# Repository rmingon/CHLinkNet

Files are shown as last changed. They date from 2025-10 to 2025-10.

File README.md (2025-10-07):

# CH32V307 Ethernet + PoE Development Board

## Overview

This project is a **custom 4-layer development board** based on the **WCH CH32V307RCT6** RISC-V microcontroller.  
It integrates **Ethernet connectivity**, **USB programming**, and **Power-over-Ethernet (PoE) readiness** through an external module header.

The design was fully created in **KiCad 9.0.3**, including schematic, PCB layout, and 3D mechanical validation.

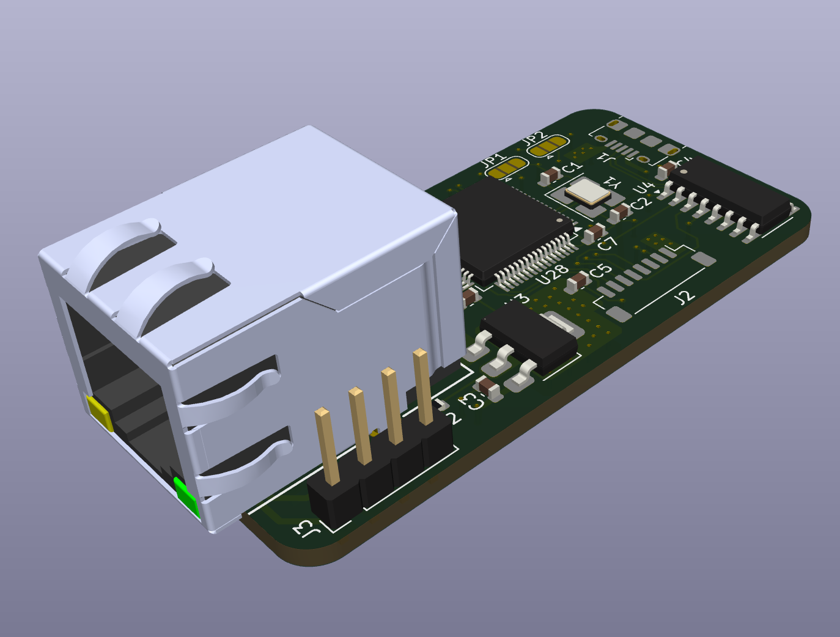
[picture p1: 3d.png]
3d


---

## Key Features

- **MCU:** WCH **CH32V307RCT6**

  - 32-bit RISC-V core @144 MHz
  - 256 KB Flash / 64 KB SRAM
  - Integrated MAC controller for Ethernet
  - USB 2.0 Full-Speed, CAN, ADC, PWM, and multiple GPIOs

- **Ethernet Interface:**

  - **HY931147C** RJ45 connector with integrated magnetics and LEDs
  - RMII interface connected to the CH32V307 MAC peripheral
  - Differential pair routing with impedance control for signal integrity

- **USB Interface:**

  - Micro-USB Type-B connector (J1)
  - **CH340C** USB-to-UART converter for serial programming/debugging
  - USB-powered operation (5 V input)

- **Power Supply:**

  - Input: **5 V** from USB or external PoE module (J3)
  - **LM1117-3.3V** linear regulator provides system 3.3 V rail
  - PoE header allows integration of a DC-DC converter (48 V → 5 V)

- **Clock System:**

  - **25 MHz crystal** (Y1) with 10 pF load capacitors
  - Supports both internal and external oscillators

- **Programming and Debugging:**

  - **1×8 header (J2)** for SWD and UART interface
  - **JP1** (BOOT0) and **JP2** (BOOT1) jumpers for boot mode selection
  - Compatible with WCHISPTool and OpenOCD

- **Status Indicators:**

  - Power LED
  - Dual user LEDs (green and yellow) connected via GPIOs with current-limiting resistors

- **PCB Details:**
  - **4-layer stack-up:**
    - Top: Signal
    - Inner 1: GND plane
    - Inner 2: 3V3 power plane
    - Bottom: Signal
  - Controlled impedance routing for RMII
  - Ground pour under high-speed signals for noise reduction
  - Rounded corners, compact form factor, and 3D-verified mechanical fit

---

## Hardware Architecture

### Power Section

- **Primary Source:** USB 5 V from J1
- **Secondary Source:** PoE module input via J3 header
- **Voltage Regulation:**
  - U3 (LM1117-3.3V) converts 5 V → 3.3 V
  - C4–C6 ensure low-noise decoupling near MCU and PHY
  - Separate power planes on inner layers for 3.3 V and 5 V distribution

### Ethernet Section

- **U1: HY931147C RJ45 connector** with built-in magnetics
- Connected to MCU’s RMII interface pins (TXD, RXD, CRS, REF_CLK, etc.)
- Controlled-impedance differential pairs routed on top layer, referenced to inner GND plane
- Shield and chassis ground isolated via filtering for EMI reduction

### USB-to-UART Interface

- **U4: CH340C** converts USB signals to UART for MCU programming
- Connected to TX_PROG and RX_PROG pins on CH32V307
- Includes pull-up and filtering capacitors for reliable USB operation

### Clock and Reset Circuit

- **Y1: 25 MHz crystal** connected to OSC_IN/OSC_OUT
- **JP1/JP2 jumpers** configure MCU boot mode (Flash, System Memory, SRAM)
- **NRST pin** accessible via programming header (J2)

### Programming Header (J2)

| Pin | Signal | Description |
| :-- | :--- | :--- |
| 1 | GND | Ground |
| 2 | +3V3 | Power reference |
| 3 | RST | MCU Reset |
| 4 | RX_PROG  | UART RX |
| 5 | TX_PROG  | UART TX |
| 6 | SWCLK | SWD Clock |
| 7 | SWDIO | SWD Data |
| 8 | NC / RES | Reserved |

---

## PCB Layout Highlights

- **4-layer design** with solid GND plane and 3V3 power plane
- **Short and symmetric differential routing** for Ethernet and USB signals
- **Via stitching** used to maintain continuous ground reference around high-speed nets
- **Thermal reliefs** on power pads for manufacturability
- **Decoupling capacitors** placed directly next to MCU VDD and PHY pins
- **RJ45 positioned at board edge** for easy cable insertion and mechanical stability

---

## Software & Toolchain

- **Toolchain:**

  - [WCH RISC-V GCC](https://www.wch.cn/downloads/CH32V307.html)
  - [WCHISPTool](https://www.wch.cn/downloads/WCHISPTool.html)
  - [MounRiver Studio](https://www.mounriver.com/)
  - Optional: [OpenOCD](https://openocd.org/) for SWD programming

- **Boot Modes:**
  | BOOT0 | BOOT1 | Boot Mode |
  |:------|:------|:-----------|
  | 0 | 0 | Boot from Flash |
  | 1 | 0 | Boot from System Memory (USB/UART bootloader) |
  | 0 | 1 | Boot from SRAM |

- **Programming Interfaces:**
  - Via USB (CH340C)
  - Via SWD header (J2) using a WCH-Link, J-Link, or OpenOCD adapter

---

## Design Considerations

- Ethernet differential pairs tuned to **50 Ω single-ended / 100 Ω differential impedance**
- Separate **power and ground planes** to minimize noise coupling
- **Short return paths** for high-speed signals
- **ESD protection** recommended on USB and RJ45 lines in next revision
- Provision for **PoE DC-DC converter module** (48 V → 3.3 V)

---

## Future Improvements

- Integrate **onboard PoE power converter**
- Add **ESD suppression arrays** on USB/Ethernet ports
- Replace LM1117 with a **buck converter** for improved efficiency
- Add **test points** for easier debugging and signal probing

---

## License

This project is released under the **CERN Open Hardware License – Strongly Reciprocal (CERN-OHL-S v2)**.  
You are free to study, modify, produce, and distribute this design, provided derivatives remain open-source under the same license.

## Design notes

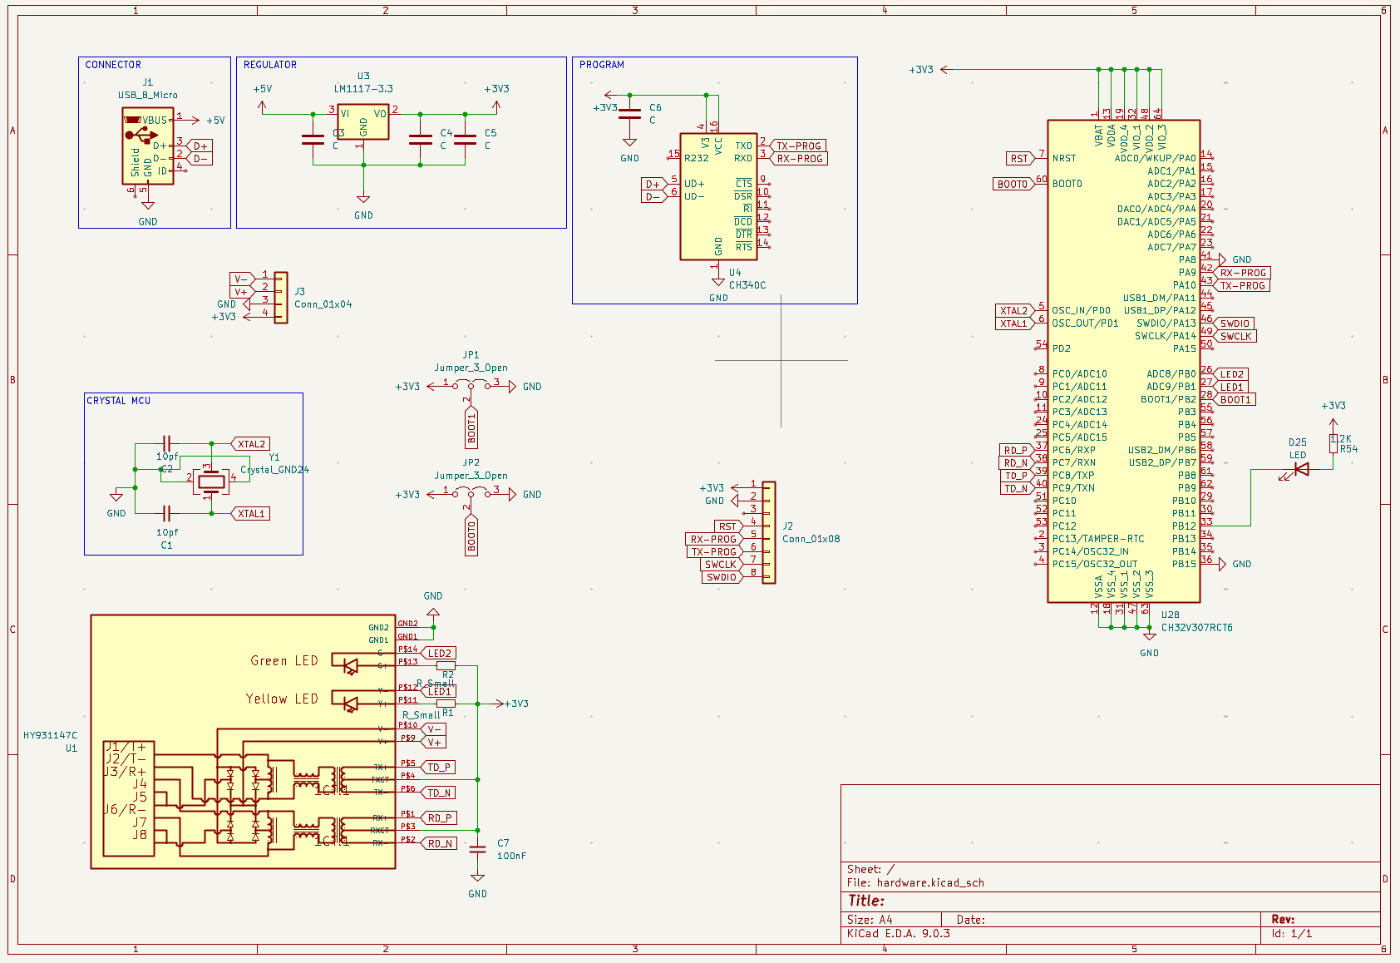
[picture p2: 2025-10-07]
schematic.png

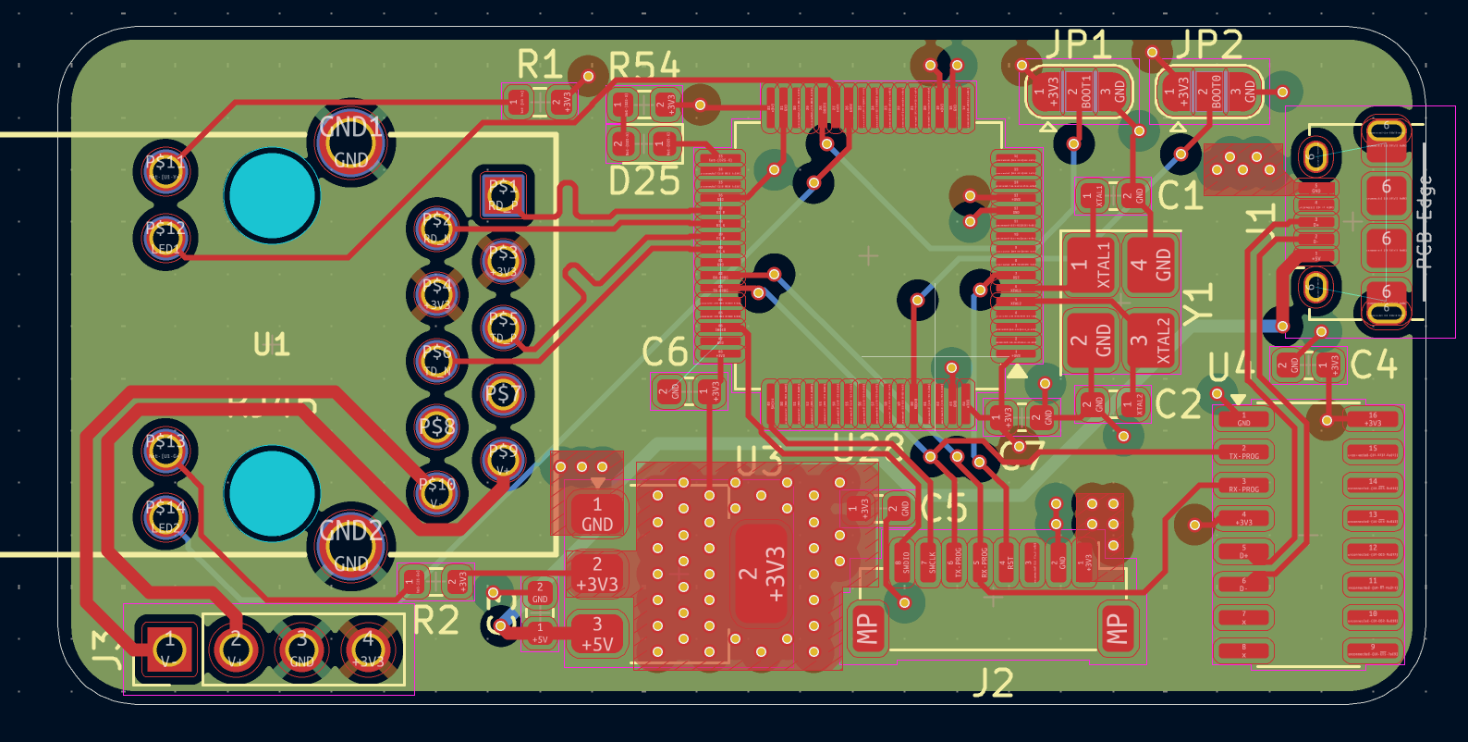
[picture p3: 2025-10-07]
pcb.png

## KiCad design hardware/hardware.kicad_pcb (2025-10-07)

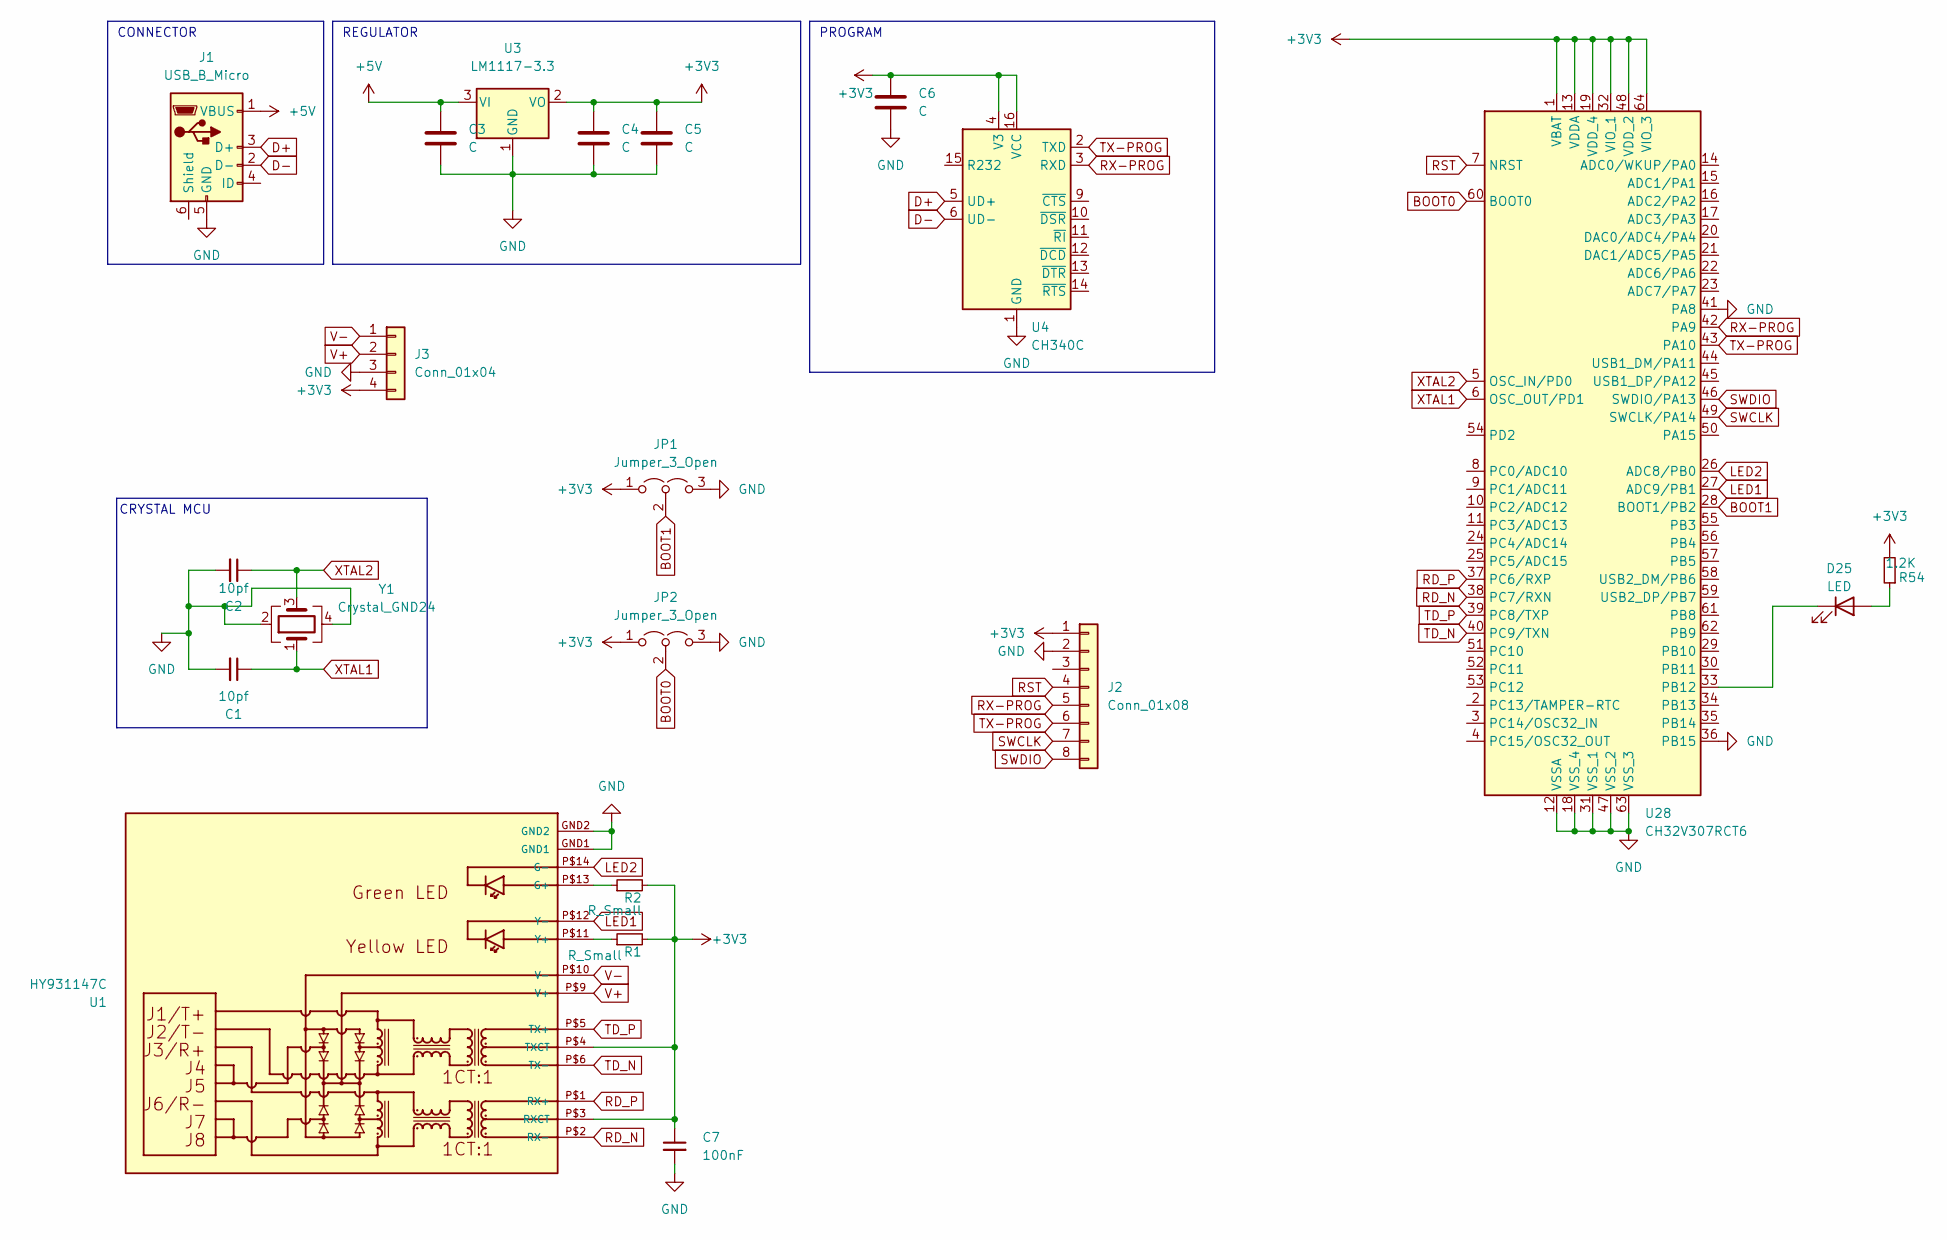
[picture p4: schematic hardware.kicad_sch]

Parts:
C1, C2: 10pf; C_0603_1608Metric; LCSC C1634
C3, C4: C; C_0603_1608Metric; LCSC C14663
C5, C6: C; C_0603_1608Metric; LCSC C15849
C7: 100nF; C_0603_1608Metric; LCSC C1634
D25: LED; LED_0603_1608Metric
J1: USB_B_Micro; USB_Micro-B_Amphenol_10118194_Horizontal; LCSC C132563
J2: Conn_01x08; JST_SH_BM08B-SRSS-TB_1x08-1MP_P1.00mm_Vertical
J3: Conn_01x04; PinHeader_1x04_P2.54mm_Vertical
JP1, JP2: Jumper_3_Open; SolderJumper-3_P1.3mm_Open_RoundedPad1.0x1.5mm
R1, R2: R_Small; R_0603_1608Metric; LCSC C2906976
R54: 1.2K; R_0603_1608Metric; LCSC C2906976
U1: HY931147C
U3: LM1117-3.3; SOT-223-3_TabPin2; LCSC C9662
U4: CH340C; SOIC-16_3.9x9.9mm_P1.27mm; LCSC C84681
U28: CH32V307RCT6; LQFP-64_10x10mm_P0.5mm; LCSC C2988083
Y1: Crystal_GND24; Crystal_SMD_3225-4Pin_3.2x2.5mm_HandSoldering; LCSC C9006

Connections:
+3V3: C4.1, C5.1, C6.1, C7.1, J2.1, J3.4, JP1.1 (A), JP2.1 (A), R1.2, R2.2, R54.2, U1.P$3 (RXCT), U1.P$4 (TXCT), U3.2 (VO), U4.4 (V3), U4.16 (VCC), U28.1 (VBAT), U28.13 (VDDA), U28.19 (VDD_4), U28.32 (VIO_1), U28.48 (VDD_2), U28.64 (VIO_3)
+5V: C3.1, J1.1 (VBUS), U3.3 (VI)
BOOT0: JP2.2 (C), U28.60 (BOOT0)
BOOT1: JP1.2 (C), U28.28 (BOOT1/PB2)
D+: J1.3 (D+), U4.5 (UD+)
D-: J1.2 (D-), U4.6 (UD-)
GND: C1.2, C2.2, C3.2, C4.2, C5.2, C6.2, C7.2, J1.5 (GND), J2.2, J3.3, JP1.3 (B), JP2.3 (B), U1.GND1, U1.GND2, U3.1 (GND), U4.1 (GND), U28.12 (VSSA), U28.18 (VSS_4), U28.31 (VSS_1), U28.36 (PB15), U28.41 (PA8), U28.47 (VSS_2), U28.63 (VSS_3), Y1.2, Y1.4
LED1: U1.P$12 (Y-), U28.27 (ADC9/PB1)
LED2: U1.P$14 (G-), U28.26 (ADC8/PB0)
unnamed: D25.2 (A), R54.1
unnamed: D25.1 (K), U28.33 (PB12)
unnamed: R2.1, U1.P$13 (G+)
unnamed: R1.1, U1.P$11 (Y+)
RD_N: U1.P$2 (RX-), U28.38 (PC7/RXN)
RD_P: U1.P$1 (RX+), U28.37 (PC6/RXP)
RST: J2.4, U28.7 (NRST)
RX-PROG: J2.5, U4.3 (RXD), U28.42 (PA9)
SWCLK: J2.7, U28.49 (SWCLK/PA14)
SWDIO: J2.8, U28.46 (SWDIO/PA13)
TD_N: U1.P$6 (TX-), U28.40 (PC9/TXN)
TD_P: U1.P$5 (TX+), U28.39 (PC8/TXP)
TX-PROG: J2.6, U4.2 (TXD), U28.43 (PA10)
V+: J3.2, U1.P$9 (V+)
V-: J3.1, U1.P$10 (V-)
XTAL1: C1.1, U28.6 (OSC_OUT/PD1), Y1.1
XTAL2: C2.1, U28.5 (OSC_IN/PD0), Y1.3

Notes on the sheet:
CRYSTAL MCU
PROGRAM
CONNECTOR
REGULATOR

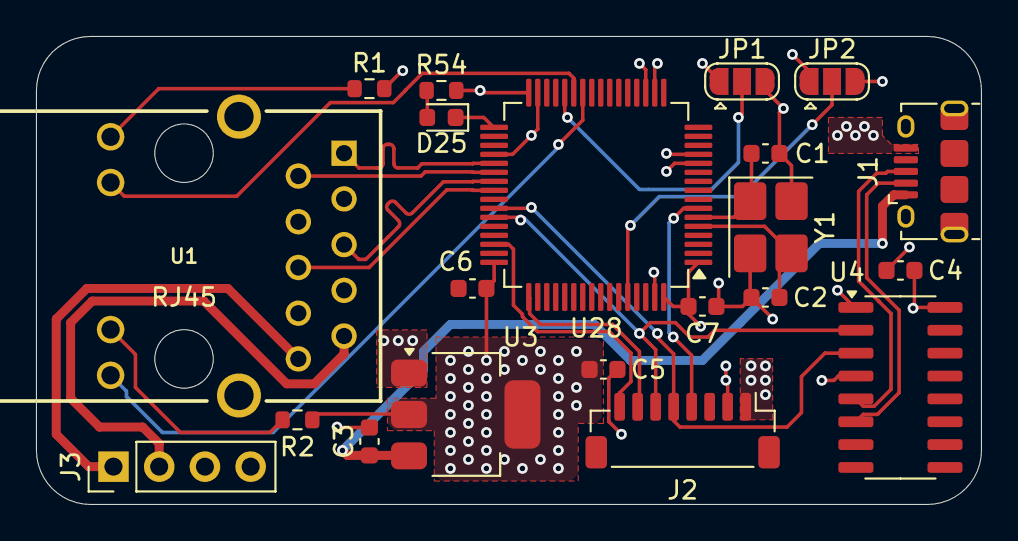
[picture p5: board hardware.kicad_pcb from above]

Board: 4 copper layers, 52.5 x 26.0 mm, 21 parts (0 on the bottom side), 26 nets.

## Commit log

2025-10-05 add minimal schematic
    [hardware.kicad_pcb, hardware.kicad_sch]
2025-10-06 differencial wiring
    [hardware.kicad_pcb, hardware.kicad_sch]
2025-10-07 wiring pcb
    [hardware.kicad_pcb, hardware.kicad_sch]
